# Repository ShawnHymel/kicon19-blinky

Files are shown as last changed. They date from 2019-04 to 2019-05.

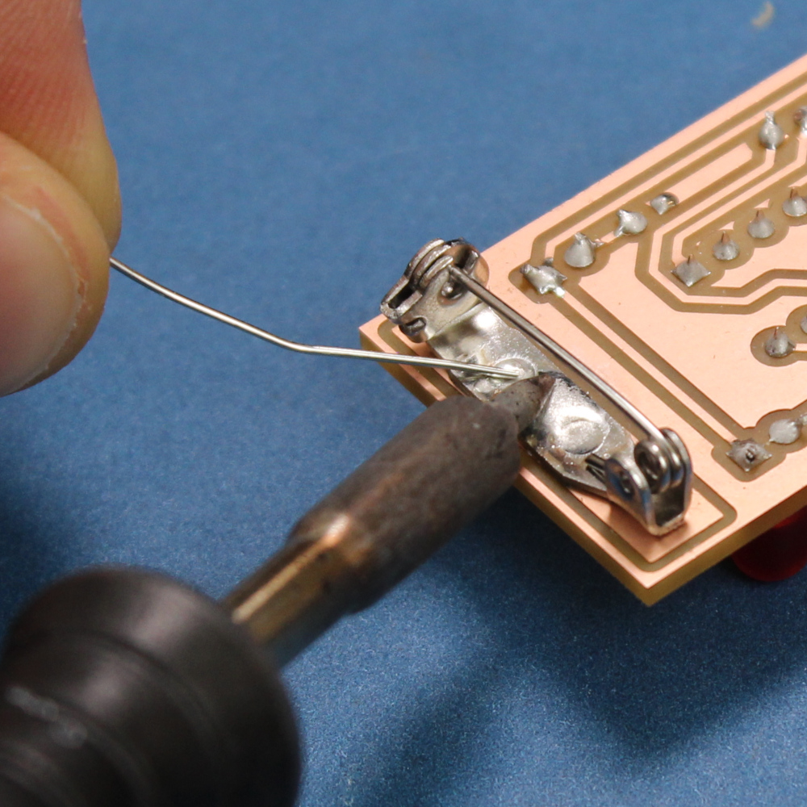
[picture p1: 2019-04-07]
images/soldering_pin.jpg

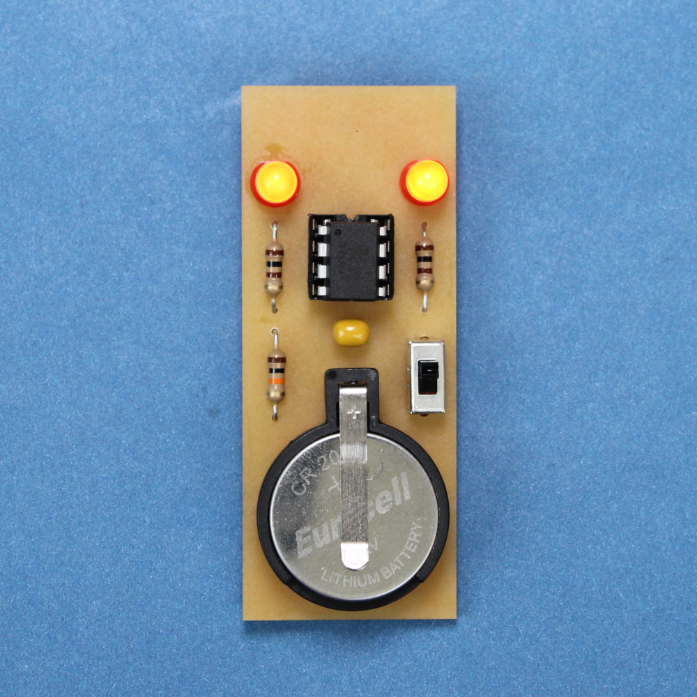
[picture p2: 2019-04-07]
images/finished_board.jpg

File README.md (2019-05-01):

Blinky Pin for KiCon 2019
=========================

Pin badge developed for KiCon 2019. Workshop used to teach people the basics of KiCad.

Getting Started
---------------

Follow the instructions found in the [Worksheet - Intro to KiCad PDF](https://github.com/ShawnHymel/kicon19-blinky/blob/master/Documentation/Worksheet%20-%20Intro%20to%20KiCad.pdf).

Bill of Materials (BOM)
-----------------------

To build the pin/badge, refer to the [BOM file found here](https://github.com/ShawnHymel/kicon19-blinky/blob/master/Hardware/kicon19-blinky-bom.csv).

License
-------

The code is beerware; if you see me at the local, and you've found the code helpful, please buy me a round!

Board schematic and layout design found in the [Hardware directory](https://github.com/ShawnHymel/kicon19-blinky/tree/master/Hardware) are [CC BY 4.0](https://creativecommons.org/licenses/by/4.0/).

[Worksheet](https://github.com/ShawnHymel/kicon19-blinky/blob/master/Documentation/Worksheet%20-%20Intro%20to%20KiCad.pdf) is [CC BY 4.0](https://creativecommons.org/licenses/by/4.0/).

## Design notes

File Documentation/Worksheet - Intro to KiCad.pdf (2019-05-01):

## Intro to KiCad

KiCon 2019 (based on KiCad 5.1.0)
Worksheet by Shawn Hymel (License: CC BY 4.0)

Name:______________________ Date:_______________________

Installation
- Navigate to kicad-pcb.org/download/ and download the installer for your OS
- Run the installer, accepting all defaults
- Wanna see video tutorials of KiCad? Go here: bit.ly/LearnKiCad
- Project files can be found here: github.com/ShawnHymel/kicon19-blinky

Schematic Capture
- Start KiCad; you should be looking at the Project Manager window
- File > New > Project, create a new project named kicon19-blinky.pro
- Click Schematic Layout Editor
- Place > Symbol, click anywhere in work area
- Search for ATtiny85-20PU, click OK
- Place anywhere within schematic sheet
- Repeat for:
- 1x Battery_Cell
- 1x SW_SPDT (for “switch”)
- 1x CAP (for “capacitor”)
- 3x R (for “resistor”)
- 2x LED
- Update component values (Right-click on symbol > Properties > Edit Value…)
- Change capacitor value from CAP to 10uF
- Change 2x resistor values from R to 100
- Change 1x resistor value from R to 10k
- Move parts around to match the schematic in the image below
- Right-click on symbol > Move to move symbols
- Right-click on symbol > Orientation > Rotate Clockwise to rotate
- Connect the components as shown in the schematic
- Place > Wire
- Click on symbol end to start wire, click on another symbol end to stop drawing wire
- Add reference designators to symbols
- Tools > Annotate Schematic
- Keep defaults, click Annotate then click Close
- The symbols should have reference designators (e.g. R1, R2)

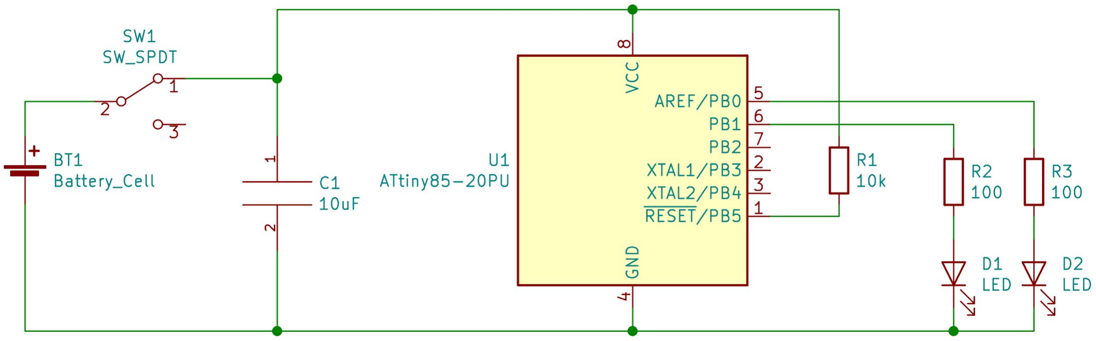
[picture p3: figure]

Assign Footprints to Symbols
- This is where we tell KiCad to associate a PCB part footprint with each schematic symbol
- Click Tools > Assign Footprints…
- Make sure only the Pin Count and Library filters are selected
- Assign BatteryHolder_Keystone_103_1x20mm footprint to Battery_Cell symbol
- In Footprint Libraries pane, select the Battery library
- In Footprint Assignments pane, select Battery_Cell symbol (BT1)
- In Filtered Footprints pane, double-click BatteryHolder_Keystone_103_1x20mm
- Assign C_Disc_D5.0mm_W2.5mm_P2.50mm to 10uF capacitor symbol
- In Footprint Libraries pane, select the Capacitor_THT library
- In Footprint Assignments pane, select 10uF symbol (C1)
- In Filtered Footprints pane, double-click C_Disc_D5.0mm_W2.5mm_P2.50mm
- Repeat this process for the rest of the symbols:
- From the LED_THT library, assign LED_D5.00mm to both LED symbols (D1, D2)
- From the Resistor_THT library, assign R_Axial_DIN0207_L6.3mm_D2.5mm_P10.16mm_Horizontal to the 10k and 100 Ohm resistors (R1, R2, R3)
- From the Button_Switch_THT library, assign SW_Slide_1P2T_CK_OS102011MS2Q to the SW_SPDT switch (SW1)
- From the Package_DIP library, assign DIP-8_W7.62mm to the ATtiny85-20PU (U1)
- Make sure your footprint assignments look like the ones below, and click OK

Generate Netlist
- A netlist tells the PCB layout software where everything is connected, according to the schematic
- Click Tools > Generate Netlist File…
- Click Generate Netlist
- Save .net file in your project directory
- Close Schematic Layout Editor

Load Netlist into PCB Layout Editor
- In the Project Manager, click PCB Layout Editor
- Click Tools > Load Netlist…
- Click the folder button in the top-right of the window
- Select your netlist file (.net), and click Open
- Click Update PCB
- All your components should be on your cursor
- Zoom in/out with your mouse wheel
- Click to place them in the center of the work area

Configure Design Rules
- Change units to inches by clicking on this button on the left bar
- Click File > Board Setup...
- In Design Rules, enter the following minimums
- In Net Classes, enter the following:
- Clearance: 20 mils
- Track Width: 20 mils
- Via Size: 32 mils
- Via Drill: 16 mils
- μVia Size: 32 mils
- μVia Drill: 16 mils
- dPair Width: 20 mils
- dPair Gap: 20 mils
- Click OK. This sets our PCB trace and drill parameters, and it should match our manufacturing process (you can get these rules from your PCB manufacturer’s website)

Organize Components
- NOTE: This is a single-sided PCB, so our components will be on the Front layer and our traces will be on the Back layer
- At the top, change the grid to 50.00 mils (1.2700 mm)
- Organize the components
- Right-click on the components, select Move or Rotate
- Try to avoid airwire crossings as much as possible
- On the right bar, click the Edge.Cuts layer to select it
- Click Place > Line, and draw a board outline around your components
- Leave 0.3 inches at top to allow for pin back
- Check your board
- It should look like this
- Outline should measure 1.0 x 2.5 inches
- Check outline dimensions with Inspect > Measure

Route Traces
- At the top, change the grid to 10.00 mils (0.2450 mm)
- Select B.Cu layer
- Route traces
- Click Route > Single Track
- Click on component through-hole to start
- Click to place bend in track
- Click on end component through-hole to end

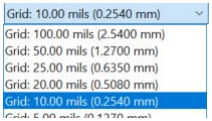
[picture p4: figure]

- You can also click on parts of a track to connect traces together
- Where each trace goes will be highlighted by its airwire
- Let the airwires guide you!
- Do not cross traces from different nets.
- Stay on the B.Cu layer
- Keep connecting component leads together until the airwires are gone
- Add a copper “filled zone” for the pin back
- Click Place > Zone

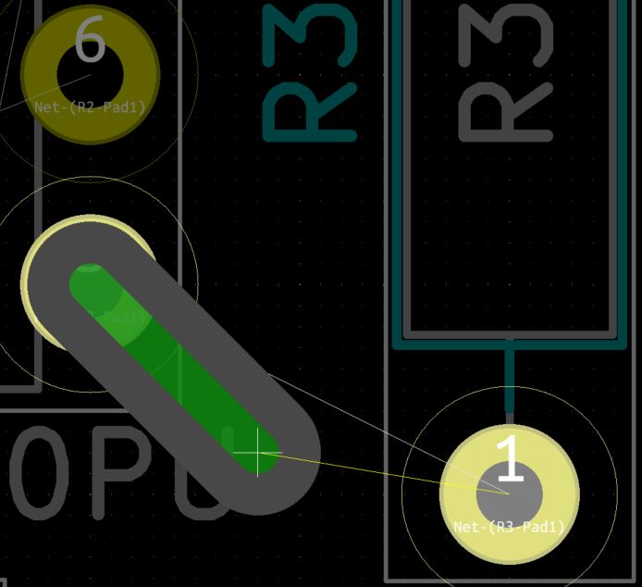
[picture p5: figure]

- Click 0.05 in. down and 0.05 in. to the right of the top-left corner of the PCB outline
- A pop-up will appear, keep all defaults, and click OK
- Press spacebar to set a temporary origin point
- Draw a 0.9 x 0.2 in. rectangle.
- Use the dx/dy markers in the bottom-right to help
- Your final board should look like this:
- Check your design
- Click Inspect > Design Rules Checker
- Click Run DRC
- You should see 4 errors pointing at the switch footprint, as the holes are too close together (but still OK)
- You should also see 1 error showing the battery footprint has an incorrect courtyard (this is also OK)
- Find and fix any other errors you might see
- Click List Unconnected
- You should see no unconnected items
- Click Delete All Markers
- Click Close

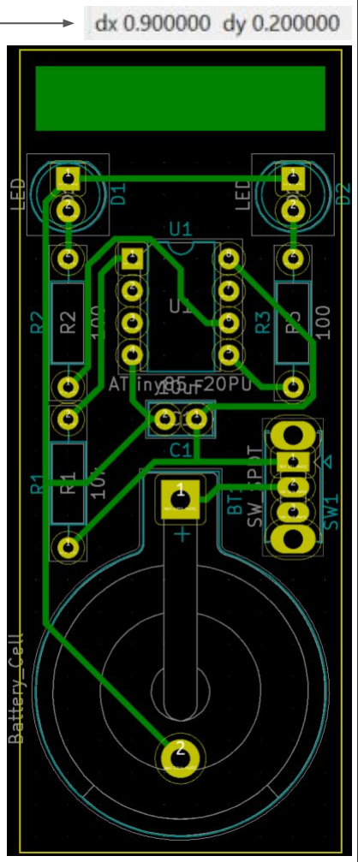
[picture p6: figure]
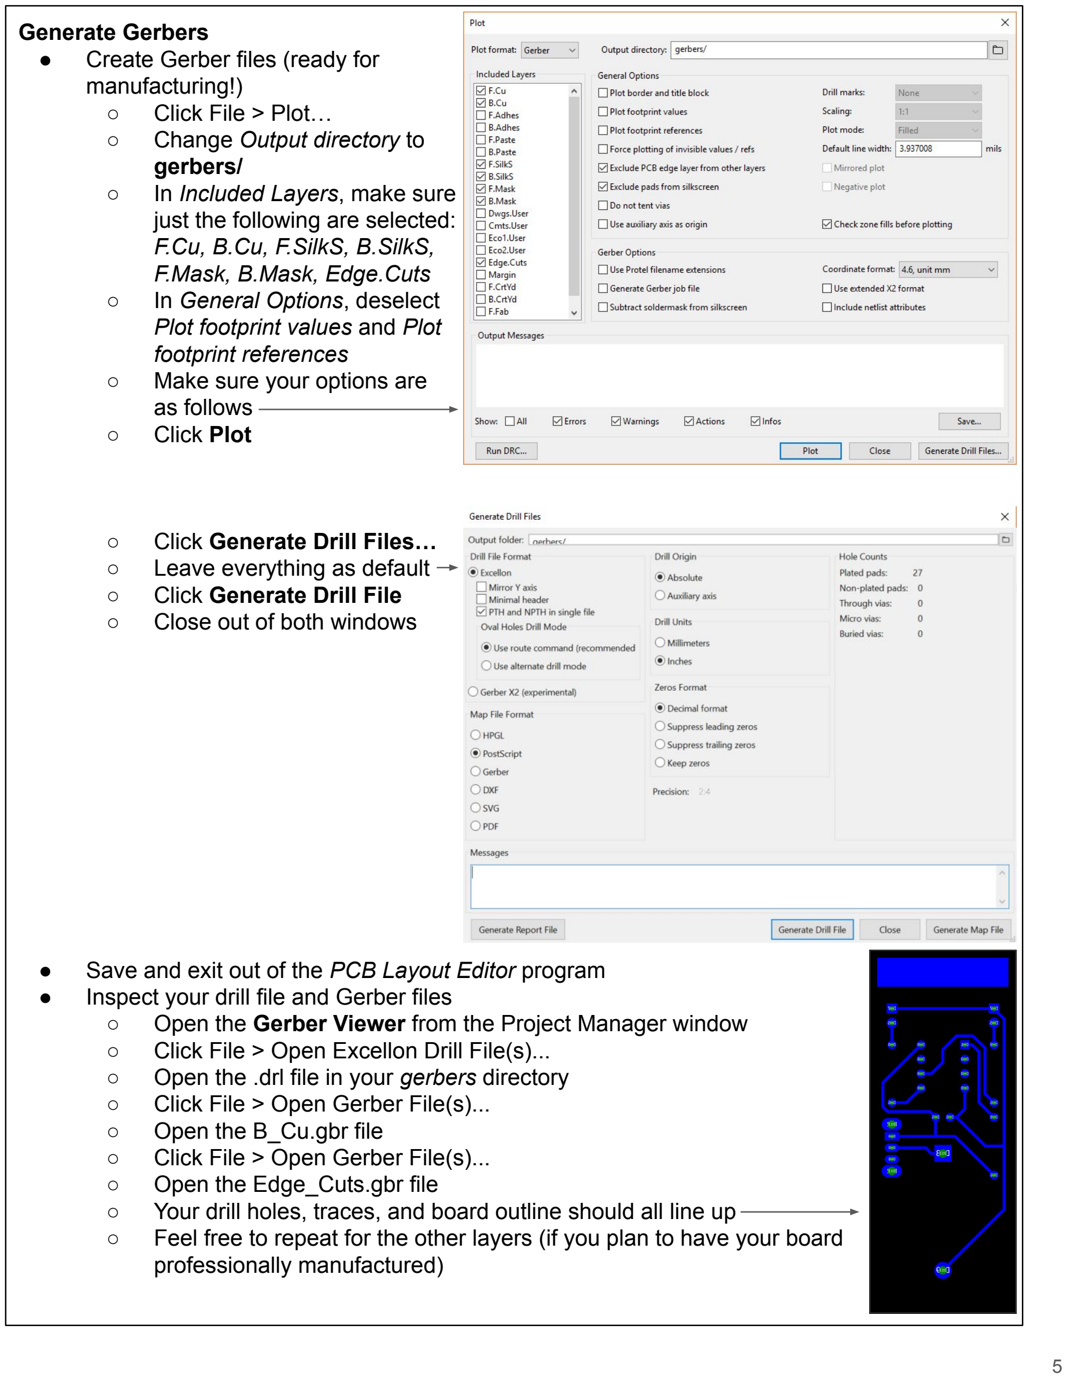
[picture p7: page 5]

Generate Gerbers
- Create Gerber files (ready for manufacturing!)
- Click File > Plot…
- Change Output directory to gerbers/
- In Included Layers, make sure just the following are selected: F.Cu, B.Cu, F.SilkS, B.SilkS, F.Mask, B.Mask, Edge.Cuts
- In General Options, deselect Plot footprint values and Plot footprint references
- Make sure your options are as follows
- Click Plot
- Click Generate Drill Files…
- Leave everything as default
- Click Generate Drill File
- Close out of both windows
- Save and exit out of the PCB Layout Editor program
- Inspect your drill file and Gerber files
- Open the Gerber Viewer from the Project Manager window
- Click File > Open Excellon Drill File(s)...
- Open the .drl file in your gerbers directory
- Click File > Open Gerber File(s)...
- Open the B_Cu.gbr file
- Click File > Open Gerber File(s)...
- Open the Edge_Cuts.gbr file
- Your drill holes, traces, and board outline should all line up
- Feel free to repeat for the other layers (if you plan to have your board professionally manufactured)

Assemble Board
- Place components on the front side (the side without copper)
- Refer to this assembly guide
- Note that U1 should be the DIP socket
- Solder component leads on back side (side with copper)
- Hold the safety pin to the copper rectangle on the back side with a soldering iron and feed solder into the pin’s holes
- Program the ATtiny85 with the fade-blinky Arduino program
- Code found in GitHub project repository
- This can be done with another Arduino
- Alternatively, this board can help: sparkfun.com/products/11801
- Test it!
- Insert the ATtiny85 into the socket
- Insert the battery
- Flip the switch
- Things should blink!

Make Your Boards
- Send your boards off for fabrication!
- One good place is oshpark.com
- Note that this is a single-sided board, which might save you on costs
- Another option: mill boards yourself (if you have a CNC mill)
- The Bantam Tools Desktop Milling Machine is a good option

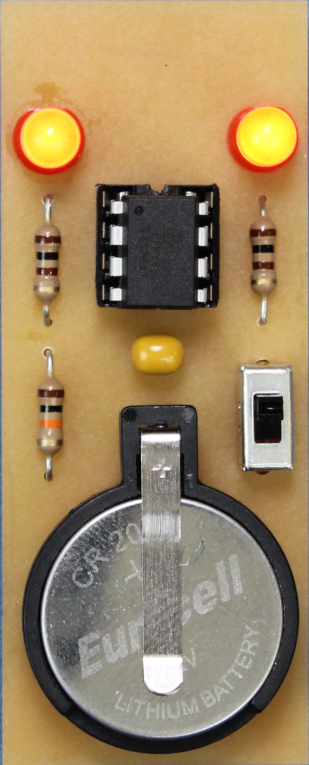
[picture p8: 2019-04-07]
images/finished_board_cropped.jpg

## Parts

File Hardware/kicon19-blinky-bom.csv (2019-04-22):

Part | Reference | Quantity | Value | MPN | DK Part No. | Part Page
Battery Holder | BT1 | 1 |  | 103 | 36-103-ND | https://www.digikey.com/product-detail/en/keystone-electronics/103/36-103-ND/331620
Battery | BT1 | 1 |  |  | P189-ND | https://www.digikey.com/product-detail/en/panasonic-bsg/CR2032/P189-ND/31939
Switch | SW1 | 1 |  | OS102011MS2QN1 | CKN9565-ND | https://www.digikey.com/product-detail/en/c-k/OS102011MS2QN1/CKN9565-ND/411602
Capacitor | C1 | 1 | 10 uF | C324C106K3R5TA | 399-13950-ND | https://www.digikey.com/product-detail/en/kemet/C324C106K3R5TA/399-13950-ND/6562361
DIP Socket | U1 | 1 |  | A 08-LC-TT | AE9986-ND | https://www.digikey.com/product-detail/en/assmann-wsw-components/A-08-LC-TT/AE9986-ND/821740
ATtiny85 | U1 | 1 |  | ATTINY85-20PU | ATTINY85-20PU-ND | https://www.digikey.com/product-detail/en/microchip-technology/ATTINY85-20PU/ATTINY85-20PU-ND/735469
Resistor | R1 | 1 | 10k | CF14JT10K0 | CF14JT10K0CT-ND | https://www.digikey.com/product-detail/en/stackpole-electronics-inc/CF14JT10K0/CF14JT10K0CT-ND/1830374
Resistor | R2 R3 | 2 | 100 | CF14JT100R | CF14JT100RCT-ND | https://www.digikey.com/product-detail/en/stackpole-electronics-inc/CF14JT100R/CF14JT100RCT-ND/1830327
LED | D1 D2 | 2 | RED | WP7113ID | 754-1264-ND | https://www.digikey.com/product-detail/en/kingbright/WP7113ID/754-1264-ND/1747663

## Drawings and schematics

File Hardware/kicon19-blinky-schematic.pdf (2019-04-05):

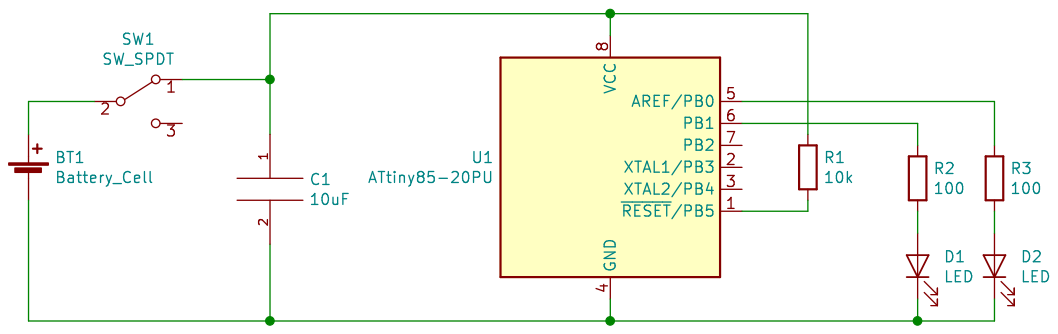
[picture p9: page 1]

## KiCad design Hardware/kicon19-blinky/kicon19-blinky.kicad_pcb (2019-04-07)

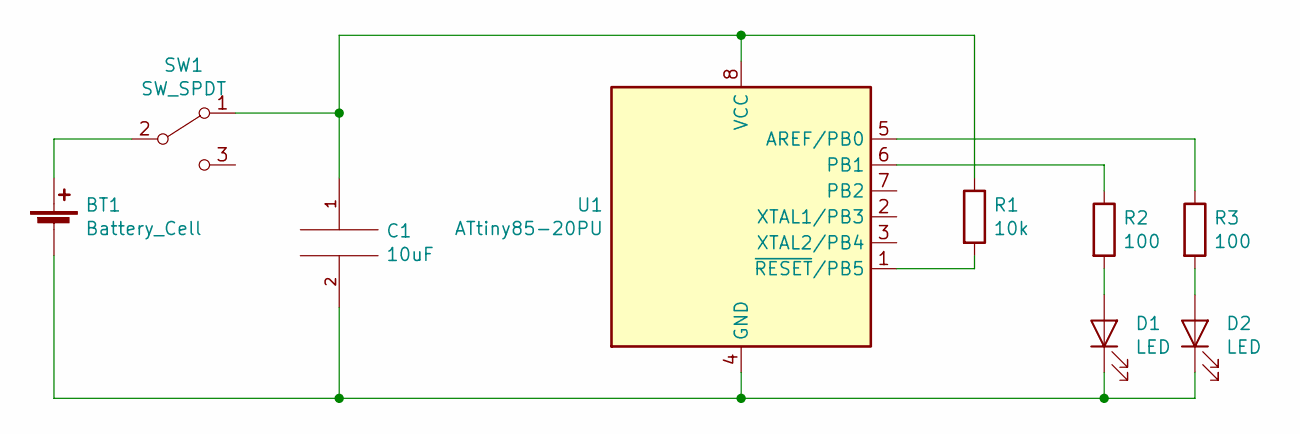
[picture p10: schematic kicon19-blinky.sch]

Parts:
BT1: Battery_Cell; BatteryHolder_Keystone_103_1x20mm
C1: 10uF; C_Disc_D5.0mm_W2.5mm_P2.50mm
D1, D2: LED; LED_D5.0mm
R1: 10k; R_Axial_DIN0207_L6.3mm_D2.5mm_P10.16mm_Horizontal
R2, R3: 100; R_Axial_DIN0207_L6.3mm_D2.5mm_P10.16mm_Horizontal
SW1: SW_SPDT; SW_Slide_1P2T_CK_OS102011MS2Q
U1: ATtiny85-20PU; DIP-8_W7.62mm

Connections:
unnamed: BT1.1 (+), SW1.2 (B)
unnamed: BT1.2 (-), C1.2, D1.1 (K), D2.1 (K), U1.4 (GND)
unnamed: C1.1, R1.1, SW1.1 (A), U1.8 (VCC)
unnamed: D1.2 (A), R2.2
unnamed: D2.2 (A), R3.2
unnamed: R1.2, U1.1 (~RESET~/PB5)
unnamed: R2.1, U1.6 (PB1)
unnamed: R3.1, U1.5 (AREF/PB0)

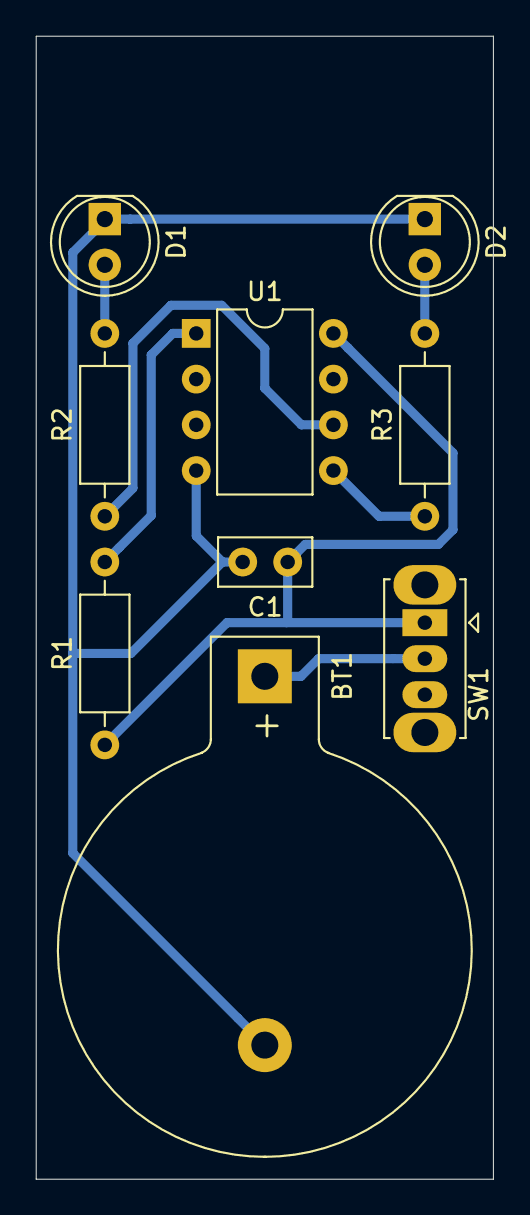
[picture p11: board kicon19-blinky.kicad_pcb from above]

Board: 2 copper layers, 25.4 x 63.5 mm, 9 parts (0 on the bottom side), 8 nets.

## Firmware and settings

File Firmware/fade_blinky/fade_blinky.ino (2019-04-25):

/**
 * Basic fade blinky for ATtiny85
 * Author: Shawn Hymel
 * Date: April 6, 2019
 * 
 * Add board manager: 
 * https://raw.githubusercontent.com/damellis/attiny/ide-1.6.x-boards-manager/package_damellis_attiny_index.json
 * 
 * Install "attiny" board definitions.
 * 
 * Settings:
 *  Board: ATtiny25/45/85
 *  Processor: ATtiny85
 *  Clock: Internal 1 MHz
 * 
 * Beerware!
 */

#include <avr/sleep.h>
#include <avr/wdt.h>

const int LED0 = 0;
const int LED1 = 1;

const int WAIT_TIME = 50;     // Time (ms) between LED updated
const int OFF_TIME = 1000;    // Time (ms) LED is off

// Perceived linear fade scale
const uint8_t PWM_TABLE_SIZE = 30;
const uint8_t pwm_table[PWM_TABLE_SIZE] PROGMEM = { 
                                        0,   1,   2,   3,   4,
                                        5,   6,   7,   8,   9,
                                       10,  11,  14,  16,  19,  
                                       23,  27,  32,  38,  45,  
                                       54,  64,  76,  90, 107, 
                                      128, 151, 180, 214, 248}; 

// Interrupt Service Routine (Watchdog Timer)
ISR(WDT_vect) {

  // Disable Watchdog Timer
  wdt_reset();                        // Reset watchdog
  MCUSR &= ~(1 << WDRF);              // Make sure flag is cleared
  WDTCR |= (1 << WDCE) | (1 << WDE);  // Special operation to let us disable WDT
  WDTCR = 0x00;                       // Turn off WDT*/
}

// Pulse LED slowly on and off once
void pulseLED() {
  
  // Fade on
  for ( int8_t i = 0; i < PWM_TABLE_SIZE; i++ ) {
    analogWrite(LED0, pgm_read_byte(&pwm_table[i]));
    analogWrite(LED1, pgm_read_byte(&pwm_table[i]));
    delay(WAIT_TIME);
  }

  // Fade off
  for ( int8_t i = PWM_TABLE_SIZE - 1; i >= 0; i-- ) {
    analogWrite(LED0, pgm_read_byte(&pwm_table[i]));
    analogWrite(LED1, pgm_read_byte(&pwm_table[i]));
    delay(WAIT_TIME);
  }
}

void setup() {

  // Configure pins
  pinMode(LED0, OUTPUT);
  pinMode(LED1, OUTPUT);

  // Disable ADC (must be before writing to PRR or ADC will be stuck on)
  ADCSRA = 0;

  // Disable power to peripherals via PRR (Timer1, USI, ADC)
  PRR = (1 << PRTIM1) | (1 << PRUSI) | (1 << PRADC);

}

void loop() {

  // Do the thing
  pulseLED();

  // Configure Watchdog Timer
  uint8_t wdt_timeout = (1 << WDP2) | (1 << WDP1) | (1 << WDP0); // 1 s timeout
  cli();                              // Disable interrupts
  wdt_reset();                        // Reset watchdog
  MCUSR = 0;                          // Clear reset flags
  WDTCR = (1 << WDCE) | (1 << WDE);   // Special operation to change prescaler
  WDTCR = (1 << WDIE) | wdt_timeout;  // Enable interrupts, set timeout
  sei();                              // Enable interrupts
  
  // Sleep sequence
  set_sleep_mode(SLEEP_MODE_PWR_DOWN);  // Only INT0, USI, and WDT can wake
  cli();                                // Disable interrupts
  sleep_enable();                       // Set Sleep Enable bit in MCUCR
  sei();                                // Enable interrupts
  sleep_cpu();                          // Go to sleep
  
  // -> Wake up here <-

  // Disable sleeping
  sleep_disable();     // Clear Sleep Enable bit in MCUCR
}

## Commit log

2019-04-05 Initial schematic and part placement
    [kicon19-blinky.kicad_pcb, kicon19-blinky.sch]
2019-04-07 Finished board, added Arduino program
    [kicon19-blinky-B_Cu.gbr, kicon19-blinky-B_Mask.gbr, kicon19-blinky-B_SilkS.gbr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]
2019-04-07 Updated Arduino code for more linear blink
    [kicon19-blinky.kicad_pcb]
2019-04-22 Reorganized folders
    [kicon19-blinky-bom.csv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]
2019-04-25 Updated sketch for low power. Added worksheet.
    [kicon19-blinky-B_Cu.gbr, kicon19-blinky-Edge_Cuts.gbr]
2019-04-26 Added battery lib
